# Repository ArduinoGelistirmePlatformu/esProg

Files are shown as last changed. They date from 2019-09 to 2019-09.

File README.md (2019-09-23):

# esProg
esProg AVR Programmer V:1.1

Bilgisayar Gerektirmeden AVR Projelerinize HEX Yükleyebilir ve Fuses Ayarlarını Yapabilirsiniz.

ilerleyen Zamanda Microchip Ve Stm Ailesinide eklemeyi Düşünüyorum.

Arduino Geliştirme Platformu: https://www.facebook.com/groups/Arduino.Pic

Video: https://www.youtube.com/watch?v=lhsaVAEl87k&t=31s

Website: https://espprog.blogspot.com/

# Programmer Device Family
 ATtiny13A
 ATtiny24
 ATtiny44
 ATtiny84
 ATtiny25
 ATtiny45
 ATtiny85
 ATtiny2313A
 ATtiny4313
 ATmega8A
 ATmega48PA
 ATmega88PA
 ATmega168PA
 ATmega168V
 ATmega328P
 ATmega328PB
 ATmega328
 ATmega164P
 ATmega324P
 ATmega644P
 ATmega640
 ATmega1280
 ATmega1281
 ATmega2560
 ATmega2561
 At90USB82
 At90USB162
 ATmega8U2
 ATmega16U2
 ATmega32U2
 ATmega16U4
 ATmega32U4
 ATmega1284P
 ATmega1284
 ATmega64rfr2
 ATmega128rfr2
 ATmega256rfr2

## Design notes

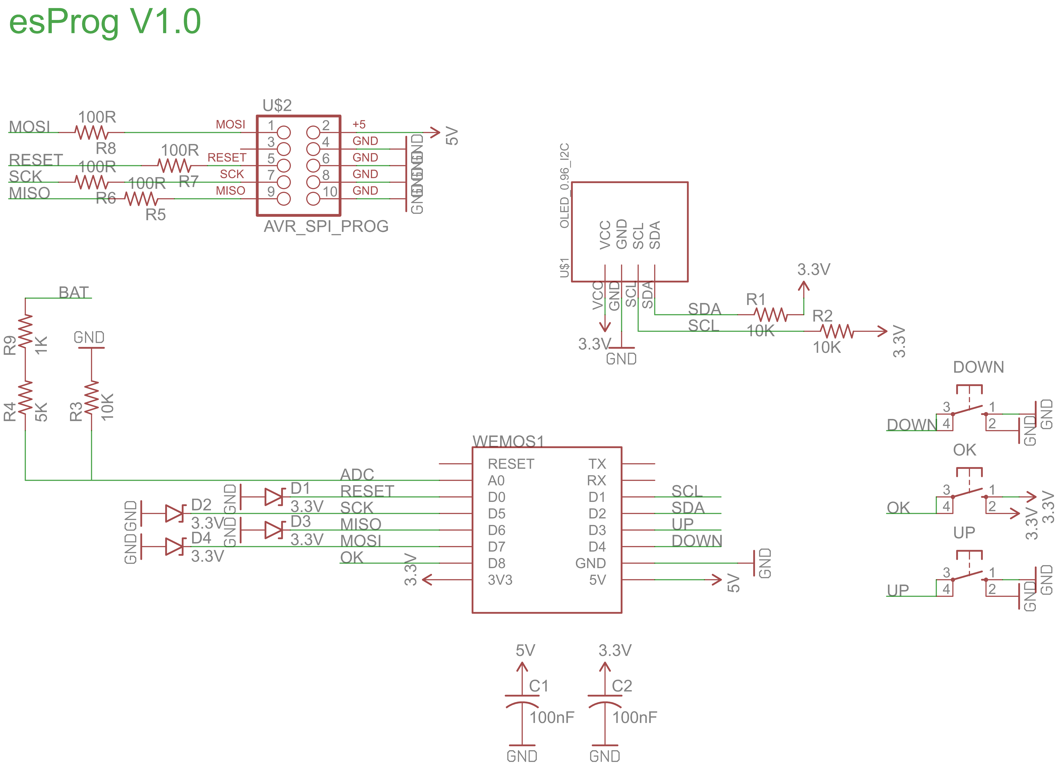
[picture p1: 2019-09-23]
Schematic/Schematic.PNG

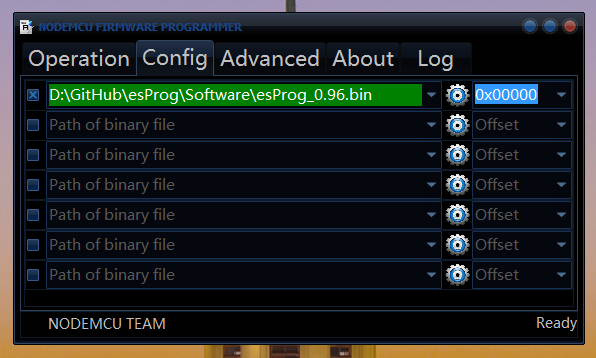
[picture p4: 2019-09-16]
Updater/EspFlasher/esProg Update 2.PNG

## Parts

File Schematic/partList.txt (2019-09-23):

Partlist

Exported from untitled.sch at 23.09.2019 10:48

EAGLE Version 7.7.0 Copyright (c) 1988-2016 CadSoft

Assembly variant: 

Part     Value          Device          Package       Library                Sheet

C1       100nF          C-USC0805K      C0805K        adafruit               1
C2       100nF          C-USC0805K      C0805K        adafruit               1
D1       3.3V           DIODE-ZENER3.3V SOD-323       SparkFun-DiscreteSemi  1
D2       3.3V           DIODE-ZENER3.3V SOD-323       SparkFun-DiscreteSemi  1
D3       3.3V           DIODE-ZENER3.3V SOD-323       SparkFun-DiscreteSemi  1
D4       3.3V           DIODE-ZENER3.3V SOD-323       SparkFun-DiscreteSemi  1
DOWN                    10-XX           B3F-10XX      switch-omron           1
OK                      10-XX           B3F-10XX      switch-omron           1
R1       10K            R-US_R0805      R0805         adafruit               1
R2       10K            R-US_R0805      R0805         adafruit               1
R3       10K            R-US_R0805      R0805         adafruit               1
R4       6K             R-US_R0805      R0805         adafruit               1
R5       100R           R-US_R0805      R0805         adafruit               1
R6       100R           R-US_R0805      R0805         adafruit               1
R7       100R           R-US_R0805      R0805         adafruit               1
R8       100R           R-US_R0805      R0805         adafruit               1
U$1      OLED_0.96_I2C  OLED_0.96_I2C   OLED_0.96_I2C tft_1.8_1.44_oled_0.96 1
U$2      AVR_SPI_PROG   AVR_SPI_PROG    AVR_ICSP      SparkFun-Connectors    1
UP                      10-XX           B3F-10XX      switch-omron           1
WEMOS1                  WEMOS-D1-MINI   WEMOS-D1-MINI esp8266modules         1

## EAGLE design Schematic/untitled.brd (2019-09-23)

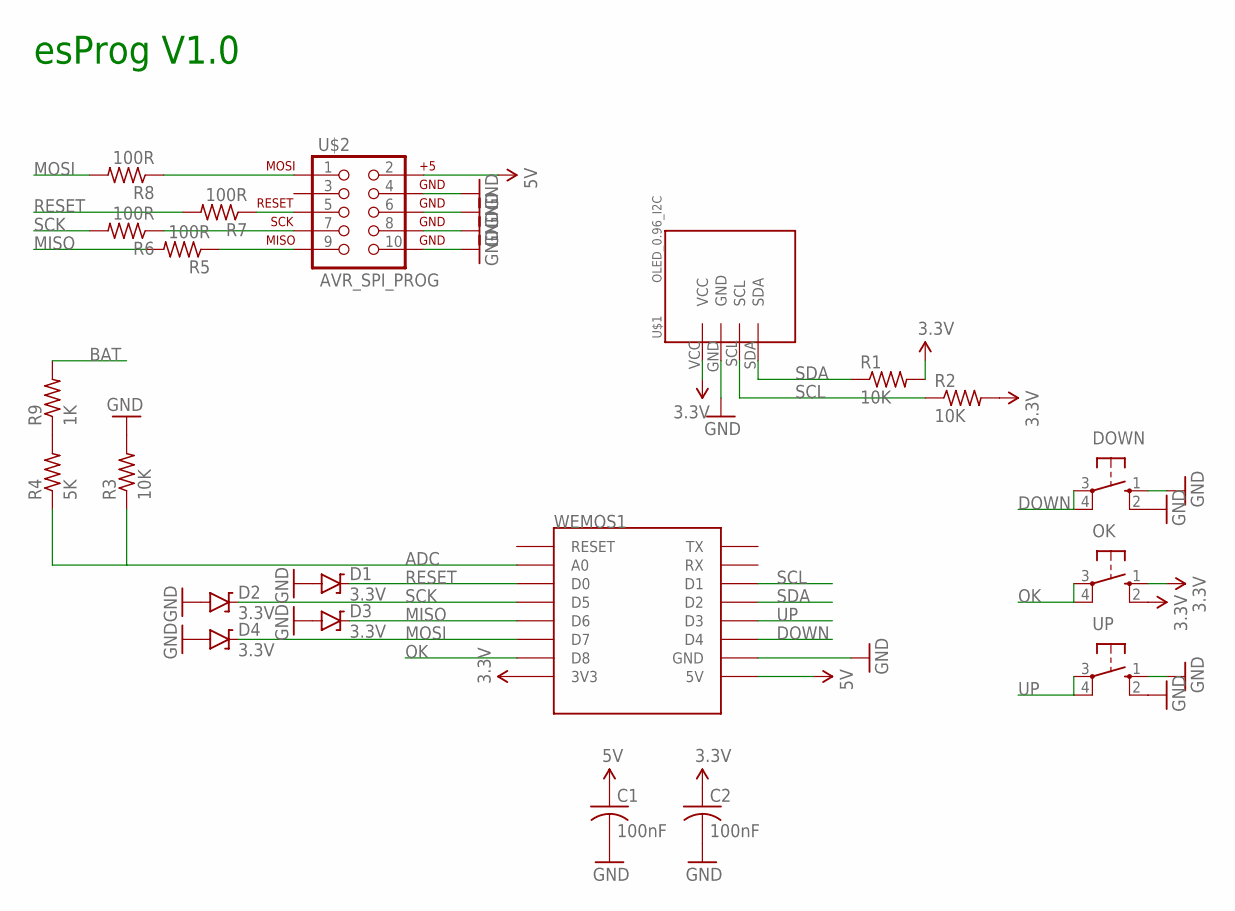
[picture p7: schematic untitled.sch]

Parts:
C1, C2: 100nF; C0805K
D1, D2, D3, D4: 3.3V; SOD-323
DOWN: 10-XX; B3F-10XX
OK: 10-XX; B3F-10XX
R1, R2, R3: 10K; R0805
R4: 5K; R0805
R5, R6, R7, R8: 100R; R0805
R9: 1K; R0805
U$1: OLED_0.96_I2C
U$2: AVR_SPI_PROG; AVR_ICSP
UP: 10-XX; B3F-10XX
WEMOS1: WEMOS-D1-MINI

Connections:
3.3V: C2.1, OK.1 (S), OK.2 (S1), R1.2, R2.2, U$1.VCC, WEMOS1.3V3
5V: C1.1, U$2.2, WEMOS1.5V
ADC: R3.1, R4.1, WEMOS1.A0
BAT: R9.2
DOWN: DOWN.3, DOWN.4 (P1), WEMOS1.D4
GND: C1.2, C2.2, D1.A, D2.A, D3.A, D4.A, DOWN.1 (S), DOWN.2 (S1), R3.2, U$1.GND, U$2.4, U$2.6, U$2.8, U$2.10, UP.1 (S), UP.2 (S1), WEMOS1.GND
MISO: D3.C, R5.2, WEMOS1.D6
MOSI: D4.C, R8.2, WEMOS1.D7
unnamed: R8.1, U$2.1
unnamed: R7.1, U$2.5
unnamed: R6.1, U$2.7
unnamed: R5.1, U$2.9
unnamed: R4.2, R9.1
OK: OK.3, OK.4 (P1), WEMOS1.D8
RESET: D1.C, R7.2, WEMOS1.D0
SCK: D2.C, R6.2, WEMOS1.D5
SCL: R2.1, U$1.SCL, WEMOS1.D1
SDA: R1.1, U$1.SDA, WEMOS1.D2
UP: UP.3, UP.4 (P1), WEMOS1.D3

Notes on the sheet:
esProg V1.0

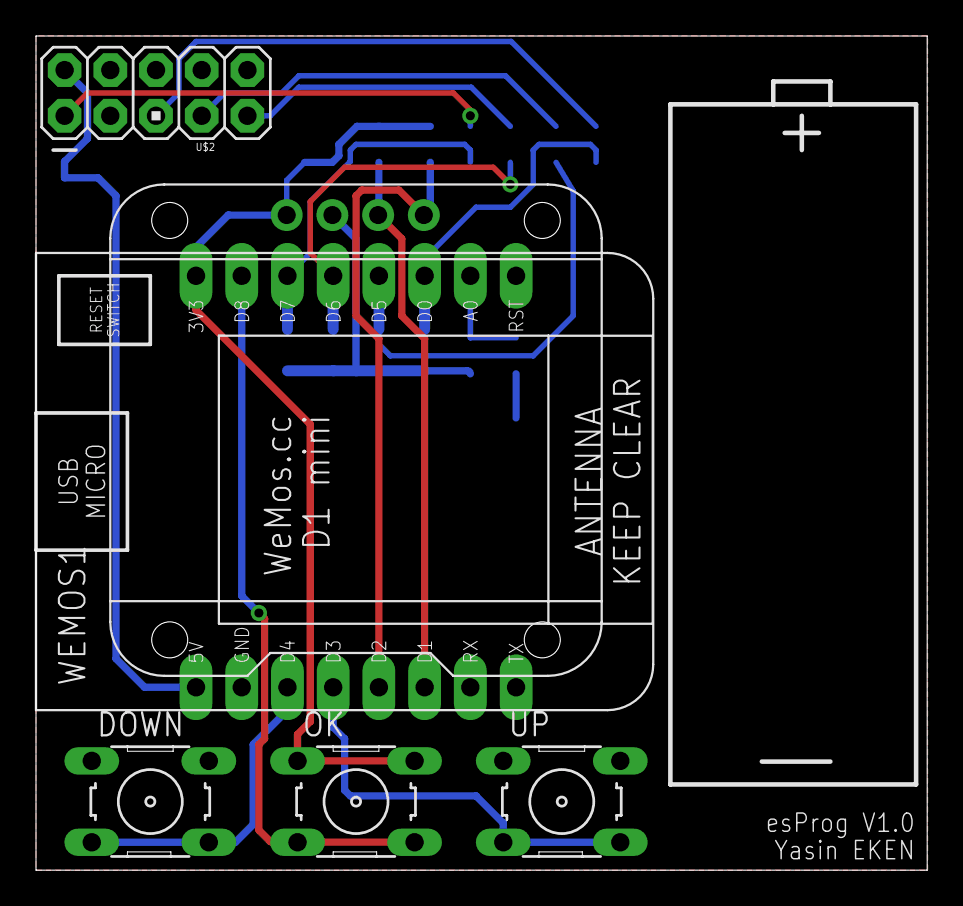
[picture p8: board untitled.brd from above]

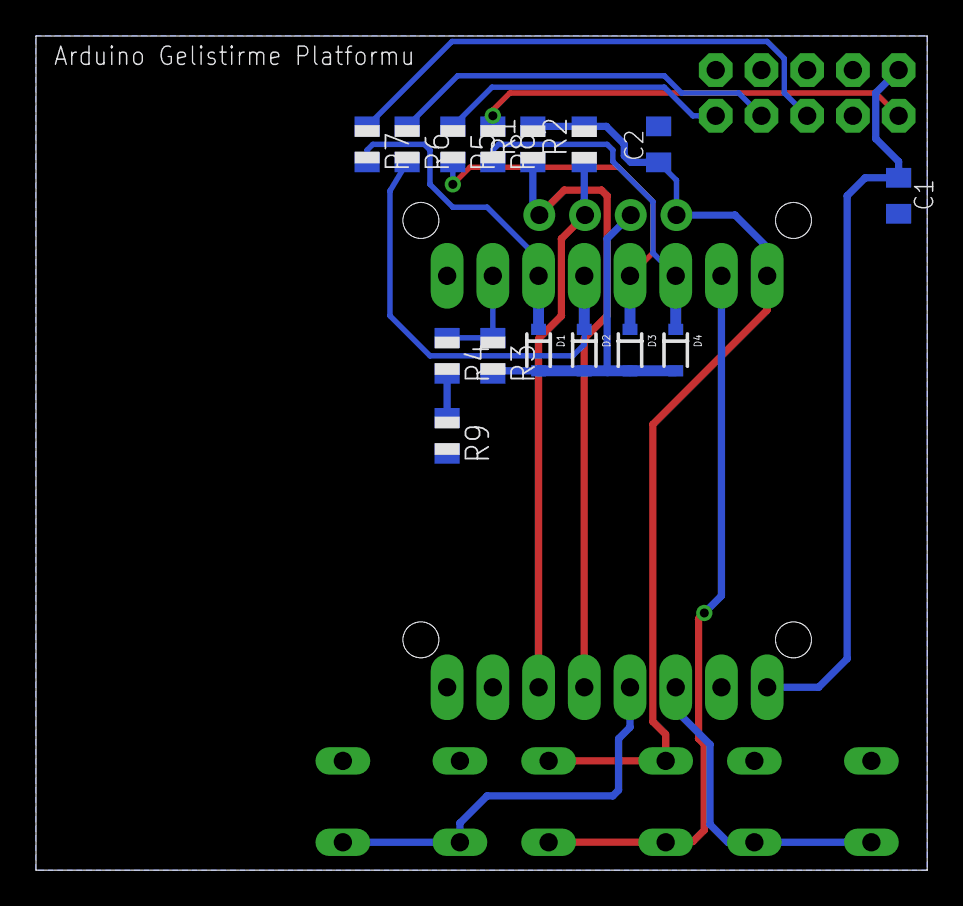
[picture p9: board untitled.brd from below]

Board: 2 copper layers, 49.5 x 46.3 mm, 21 parts (15 on the bottom side), 18 nets.

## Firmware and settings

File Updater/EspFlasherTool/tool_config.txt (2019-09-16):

ESP8266_MultiDownload_autostart1:0
ESP8266_MultiDownload_baudrate1:1
ESP8266_MultiDownload_com_port1:COM7
ESP8266_MultiDownload_autostart2:0
ESP8266_MultiDownload_com_port2:COM7
ESP8266_MultiDownload_baudrate2:1
ESP8266_MultiDownload_autostart3:0
ESP8266_MultiDownload_com_port3:COM7
ESP8266_MultiDownload_baudrate3:1
ESP8266_MultiDownload_baudrate4:1
ESP8266_MultiDownload_com_port4:COM7
ESP8266_MultiDownload_autostart4:0
ESP8266_MultiDownload_baudrate5:1
ESP8266_MultiDownload_com_port5:COM7
ESP8266_MultiDownload_autostart5:0
ESP8266_MultiDownload_com_port6:COM7
ESP8266_MultiDownload_baudrate6:1
ESP8266_MultiDownload_autostart6:0
ESP8266_MultiDownload_com_port7:COM7
ESP8266_MultiDownload_baudrate7:1
ESP8266_MultiDownload_autostart7:0
ESP8266_MultiDownload_autostart8:0
ESP8266_MultiDownload_baudrate8:1
ESP8266_MultiDownload_com_port8:COM7
ESP8266_MultiDownload_path1#empty;;;
ESP8266_MultiDownload_path0#empty;;;
ESP8266_MultiDownload_path3#empty;;;
ESP8266_MultiDownload_path2#empty;;;
ESP8266_MultiDownload_path5#empty;;;
ESP8266_MultiDownload_path4#empty;;;
ESP8266_MultiDownload_path6#empty;;;
ESP8266_MultiDownload_CRYSTAL:1
ESP8266_MultiDownload_FLASHSIZE:0
ESP8266_MultiDownload_SPICFGDIS:0
ESP8266_MultiDownload_SPIMODE:0
ESP8266_MultiDownload_SPISPEED:0
ESP8266_MultiDownload_SPIAUTOSET:0
ESP8266_MultiDownload_LOCK_SETTINGS:0
ESP8266_MultiDownload_EFUSE_MODE:1
ESP8266_MultiDownload_EFUSE_ERR_HALT:1
ESP8266_SPIDownload_baudrate1:3
ESP8266_SPIDownload_com_port1:COM5
ESP8266_SPIDownload_autostart1:0
ESP8266_SPIDownload_path6#empty;;;
ESP8266_SPIDownload_path4#empty;;;
ESP8266_SPIDownload_path5#empty;;;
ESP8266_SPIDownload_path2#empty;;;
ESP8266_SPIDownload_path3#empty;;;
ESP8266_SPIDownload_path0#selected;D:\GitHub\esProg\Software\esProg.spiffs.bin;0x100000;
ESP8266_SPIDownload_path1#empty;;;
ESP8266_SPIDownload_SPIAUTOSET:0
ESP8266_SPIDownload_SPISPEED:0
ESP8266_SPIDownload_FLASHSIZE:0
ESP8266_SPIDownload_CRYSTAL:1
ESP8266_SPIDownload_SPIMODE:0
ESP8266_SPIDownload_SPICFGDIS:0
ESP8266_SPIDownload_LOCK_SETTINGS:0
ESP8266_SPIDownload_EFUSE_ERR_HALT:1
ESP8266_SPIDownload_EFUSE_MODE:1
AUTOCALEN:0
VDD:3.3
TARGETLOWPOWER:12.000000
LIMITVAL:20.500000
TOUTADC:0
BACKOFFEN:0
FREQOFFSET:50
SETFREQEN:0
CRYFREQ:0
RFGAIN:0
TARGETPOWER6:14.000000
TARGETPOWER4:17.000000
TARGETPOWER5:16.000000
TARGETPOWER2:19.500000
TARGETPOWER3:18.500000
LOWPOWEREN:0
TARGETPOWER1:20.500000
RFINITMODE:0
BACKOFFVAL:0.000000
DIGITALGAIN:0
LIMITEN:0
ESP8266_HSPIDownloads_autostart1:0
ESP8266_HSPIDownloads_com_port1:COM7
ESP8266_HSPIDownloads_baudrate1:1
ESP8266_HSPIDownloads_path3#empty;;;
ESP8266_HSPIDownloads_path2#empty;;;
ESP8266_HSPIDownloads_path1#empty;;;
ESP8266_HSPIDownloads_path0#empty;;;
ESP8266_HSPIDownloads_path6#empty;;;
ESP8266_HSPIDownloads_path5#empty;;;
ESP8266_HSPIDownloads_path4#empty;;;
ESP8266_HSPIDownloads_SPIAUTOSET:0
ESP8266_HSPIDownloads_FLASHSIZE:0
ESP8266_HSPIDownloads_CRYSTAL:1
ESP8266_HSPIDownloads_SPIMODE:0
ESP8266_HSPIDownloads_SPICFGDIS:0
ESP8266_HSPIDownloads_SPISPEED:0
ESP8266_HSPIDownloads_LOCK_SETTINGS:0
ESP8266_HSPIDownloads_EFUSE_ERR_HALT:1
ESP8266_HSPIDownloads_EFUSE_MODE:1
TOUTVDD:1

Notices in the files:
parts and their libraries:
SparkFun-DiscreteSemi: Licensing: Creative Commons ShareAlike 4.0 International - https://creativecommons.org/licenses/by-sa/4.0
